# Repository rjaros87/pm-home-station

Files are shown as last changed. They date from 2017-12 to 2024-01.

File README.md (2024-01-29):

_Language versions:_\
EN (https://github.com/rjaros87/pm-home-station) 
PL (https://translate.googleusercontent.com/translate_c?sl=en&tl=pl&u=https://github.com/rjaros87/pm-home-station)
DE (https://translate.googleusercontent.com/translate_c?sl=en&tl=de&u=https://github.com/rjaros87/pm-home-station)

# Home use particulate matter sensor 

Since we live in big polluted cities the air quality is on a very poor level. But, the problem is not only connected to the big cities - even smaller cities and villages may suffer from air pollution.
That's why we've created this little project to let you build your own Particulate Matter monitoring station and use our open-source software so you could monitor the air quality in your place of living.

Let's live healthier life and start measuring the air quality and filtering it if necessary.

|  Android  | iPhone & Watch | Desktop |
|---|---|---|
|||<a href="https://github.com/rjaros87/pm-home-station/releases">Download and install</a>|

## Hardware Requirements

### USB version (supported by Android & Desktop apps)
- [PlanTower PMS7003](https://kamami.pl/czujniki-gazow/564008-plantower-pms7003-laserowy-czujnik-pylu-pm25.html) ~$26
- [ICD10 adapter with 10 pins(1.27 mm) to 6 pins (2.54 mm) (also called `G7 switch`)](https://kamami.pl/zlacza-inne/564553-adapter-idc10-127mm-na-zlacze-254mm-dla-czujnika-pms7003.html) ~$2
- UART to USB adapter:
  - [cheap PL2303](https://kamami.pl/konwertery-usb-uart-rs232/561382-modul-konwertera-usb-uart-rs232-ttl-z-ukladem-pl2303hx.html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) ~$2, or
  - [better quality FT232 (suggested for macOS for its superb compatibility)](https://kamami.pl/konwertery-usb-uart-rs232/561568-konwerter-usb-uart-ft232rl-waveshare.html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) ~$5
- [Female-Female wires 5 items (required for PL2303 otherwise optional since FT232 can be bought with wires already included)](https://kamami.pl/przewody-f-f/199418--przewody-polaczeniowe-f-f-roznokolorowe-17-cm-10-szt.html) ~$1-2
- [USB OTG cable](https://kamami.pl/przewody-usb/560191-przewod-adapter-microusb-otg.html) ~$1

### Bluetooth 2.0 (supported by Desktop app, possible support by Android app)
> Caution! Connectivity to the sensor over Bluetooth is currently only supported by the desktop application ran on macOS.

> Caution! If you want to connect from Apple iPhone or Apple Watch - please see Low Energy version (below)

- [PlanTower PMS7003](https://kamami.pl/czujniki-gazow/564008-plantower-pms7003-laserowy-czujnik-pylu-pm25.html) ~$26
- [ICD10 adapter with 10 pins(1.27 mm) to 6 pins (2.54 mm) (also called `G7 switch`)](https://kamami.pl/zlacza-inne/564553-adapter-idc10-127mm-na-zlacze-254mm-dla-czujnika-pms7003.html) ~$2
- [Female-Female wires 5 items](https://kamami.pl/przewody-f-f/199418--przewody-polaczeniowe-f-f-roznokolorowe-17-cm-10-szt.html) ~$1-2
- [Bluetooth UART HC-06](https://kamami.pl/moduly-bluetooth/198260-zestaw-bluetooth-z-modulem-hc-06-20edr-zasilany-3-6-6-v.html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) ~$7
- recycled old USB cable to provide power to Sensor and Bluetooth tandem

### Bluetooth Low Energy (supported by iOS app, possible support by Android app)
> Caution! Connectivity to the sensor over Bluetooth LE is currently only tested on the iOS application running on iPhone or Apple Watch. Multi-platform desktop support not planned in near feature.

- [PlanTower PMS7003](https://kamami.pl/czujniki-gazow/564008-plantower-pms7003-laserowy-czujnik-pylu-pm25.html) ~$26
- [ICD10 adapter with 10 pins(1.27 mm) to 6 pins (2.54 mm) (also called `G7 switch`)](https://kamami.pl/zlacza-inne/564553-adapter-idc10-127mm-na-zlacze-254mm-dla-czujnika-pms7003.html) ~$2
- [Bluetooth Low Energy UART HC-08](https://kamami.pl/moduly-bluetooth/562367-modhc-08-modul-bluetooth-hc-08.html) (includes wires) ~$7
- recycled old USB cable to provide power to Sensor and Bluetooth tandem

## Discount offers

You may want to use the following rebate coupon: __A9XS1FPF__ on purchases made on [KAMAMI.COM](https://kamami.com) or [KAMAMI.PL](https://kamami.pl) to get 5% OFF on orders which include PMS7003 (to be used only once for each buyer).

## Assemble the PM sensor

### USB version

1. Connect the PlanTower device with ICD10 adapter (~~like on photo below~~). 
> Caution! The pins on the PlanTower device are located in the top right corner. Numeration starts from the right top corner (1) and ends in the left bottom corner (10). 

2. Connect IDC10 adapter (bigger pins :smile:) to the UART-USB adapter. Wire connections are presented in a table below
> Caution! The adapter must have a separate VCC pin for 5V or a switch between 3.3V and 5V since the PlanTower device works on 5V voltage.

ICD10 adapter | UART-USB adapter
------------- | ----------------
VCC (5V)      | VCC (5V)
GND           | GND
RX            | TXD
TXD           | RXD

3. Connect the UART-USB adapter with a USB cable to your computer
> Caution! Refer to [this](#tested-platforms) section for remarks regarding your platform

4. Start the application and check the air quality of your environment :smile:

### Bluetooth version

1. Follow 1-3 steps of USB instruction above, but use your Bluetooth or Bluetooth LE module instead of UART-USB adapter

2. Cut off any old USB cable

3. Connect the power (5V) from USB cable or socket to Vcc and GND (2 most outside pins of USB plug, usually red 5V cable and black GND). You may need to shortcircuit data pin/wires (2 center pins) or connect them via ~200ohm resistor in order to be recognized by charger. Details can be found [here](http://pinouts.ru/Slots/USB_pinout.shtml "USB pinout").

## 3D printed enclosure

- 4x M3 x 25 machine screws with nuts are required to assemble the enclosure

- [Top v3 with hidden screws](/3d_models/top_v3_hidden_screws.stl)
- [Bottom v3 with hidden screws](/3d_models/bottom_v3_hidden_screws.stl)

or

- [Top v1](/3d_models/top_v1.stl)
- [Bottom v1](/3d_models/bottom_v1.stl)

or for FT232 usb-uart adapter

- [Top v4 with hidden screws for FT232 usb-uart adapter](/3d_models/top_v4_hidden_screws_ft232_adapter.stl)
- [Bottom v3 with hidden screws](/3d_models/bottom_v3_hidden_screws.stl)

Suggested printing parameters:
- Infill: 20%
- Resolution: 0.2
- Supports: No

> Caution! Make sure the soldered ends of the USB-UART pins (at the bottom of the adapter) are properly insulated from the sensor's metal case! Some adapters have them so long that they become too close to the sensor and may short-circuit the adapter. It's best to sand them off and use insulation tape.

## Assembly photos

The photo galleries of assembly:
- [PL2303 USB-to-UART version](https://rjaros87.github.io/pm-home-station-project/assembly/index.html "Assembly of pm-home-station using PL2303")
- [FT232 USB-to-UART version](https://rjaros87.github.io/pm-home-station-project/assembly-ft232/index.html "Assembly of pm-home-station using FT232")
- [UART-over-Bluetooth version](https://rjaros87.github.io/pm-home-station-project/assembly-bt/index.html "Assembly of pm-home-station over Bluetooth")

## Enclosure photos

The photo gallery of assembled device in 3d printed enclosure can be found [here](https://rjaros87.github.io/pm-home-station-project/enclosure/index.html "3d printed enclosure of pm-home-station").

## App Screenshots

The app screenshots gallery can be found [here](https://rjaros87.github.io/pm-home-station-project/screenshots/index.html "App screenshots of pm-home-station apps").

## Tested platforms

[See wiki page](https://github.com/rjaros87/pm-home-station/wiki/Tested-(supported)-platforms)

## Build and run

[See wiki page](https://github.com/rjaros87/pm-home-station/wiki/Building-&-Requirements)

## Contributing

[Contribution Guidelines](/CONTRIBUTING.md)

## License

[License GPL-3.0](/LICENSE)

## Authors

- [Radoslaw Gabiga](https://github.com/sanchin)
- [Radoslaw Jaros](https://github.com/rjaros87)
- [Piotr Skowronek](https://github.com/pskowronek)
- [Jerzy Łukjaniec](https://github.com/idf3d)

## Releases

The latest release versions can be found [here](https://github.com/rjaros87/pm-home-station/releases).

## Disclaimer

The information provided on this project is true and complete to the best of our knowledge. However, like various Do-It-Yourself (DIY) projects this DIY Project is at your own risk only.
As with any DIY project, lack of familiarity with the tools and process can be dangerous. We are not liable for any damage or injury resulting from the assembly or use of this project including but not limited to hardware damage, body injuries etc.

You have been warned.

<sub><sup>Google Play and the Google Play logo are trademarks of Google LLC.</sup></sub>

<sub><sup>Apple, the Apple logo, Apple Watch and iPhone are trademarks of Apple Inc., registered in the U.S. and other countries. App Store is a service mark of Apple Inc., registered in the U.S. and other countries.</sup></sub>

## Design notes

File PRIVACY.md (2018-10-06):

# Privacy Policy
The PMStation app is built as an Open Source app. This app is provided by the authors at no cost and is intended for use as is.

This page is used to inform visitors regarding our policies with the collection, use, and disclosure of Personal Information if anyone decided to use our applicaton.

If you choose to use our app, then you agree to the collection and use of information in relation to this policy. The Personal Information that we collect is used for providing and improving the service. We will not use or share your information with anyone except as described in this Privacy Policy.

### Information Collection and Use

For a better experience, while using our app, we may require you to provide us with certain personally identifiable information. The information that we request will be retained on your device and is not collected by us in any way.

The app does use third party services that may collect information used to identify you.

Link to privacy policy of third party service providers used by the app

* [Firebase Analytics](https://firebase.google.com/policies/analytics)
* [Crashlytics](https://docs.fabric.io/apple/fabric/data-privacy.html#data-collection-policies)

### Log Data

We want to inform you that whenever you use our application, in a case of an error in the app we collect data and information (through third party products) on your phone called Log Data. This Log Data may include information such as your device Internet Protocol (“IP”) address, device name, operating system version, the configuration of the app, the time and date of your use of the app, and other statistics.

### Cookies

Cookies are files with a small amount of data that are commonly used as anonymous unique identifiers. These are sent to your browser from the websites that you visit and are stored on your device's internal memory.

This app does not use these “cookies” explicitly. However, the app may use third party code and libraries that use “cookies” to collect information and improve their services.

### Security

We value your trust in providing us your Personal Information, thus we are striving to use commercially acceptable means of protecting it. But remember that no method of transmission over the internet, or method of electronic storage is 100% secure and reliable, and we cannot guarantee its absolute security.

### Links to Other Sites

This app may contain links to other sites. If you click on a third-party link, you will be directed to that site. Note that these external sites are not operated by us. Therefore, we strongly advise you to review the Privacy Policy of these websites. We have no control over and assume no responsibility for the content, privacy policies, or practices of any third-party sites or services.

### Changes to This Privacy Policy

We may update our Privacy Policy from time to time. Thus, you are advised to review this page periodically for any changes. We will notify you of any changes by posting the new Privacy Policy on this page. These changes are effective immediately after they are posted on this page.

### Contact Us

If you have any questions or suggestions about our Privacy Policy, do not hesitate to contact us.

This privacy policy page was created at [privacypolicytemplate.net](https://privacypolicytemplate.net/) and modified/generated by [App Privacy Policy Generator](https://app-privacy-policy-generator.firebaseapp.com/)

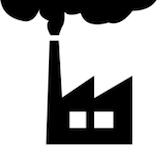
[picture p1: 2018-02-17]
iOS/PMMonitor/About.png

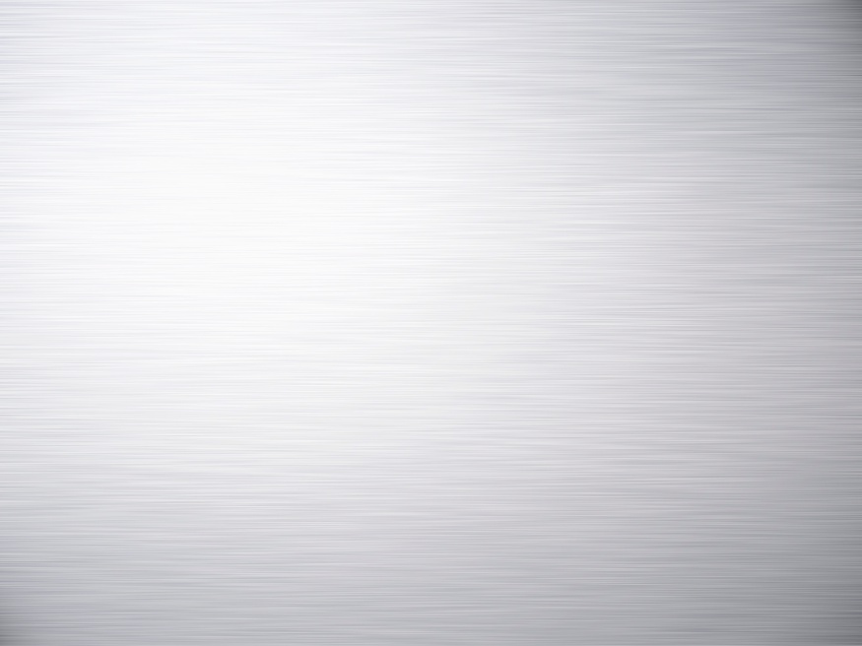
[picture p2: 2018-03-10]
desktop/src/main/resources/pmstation/bg.jpg

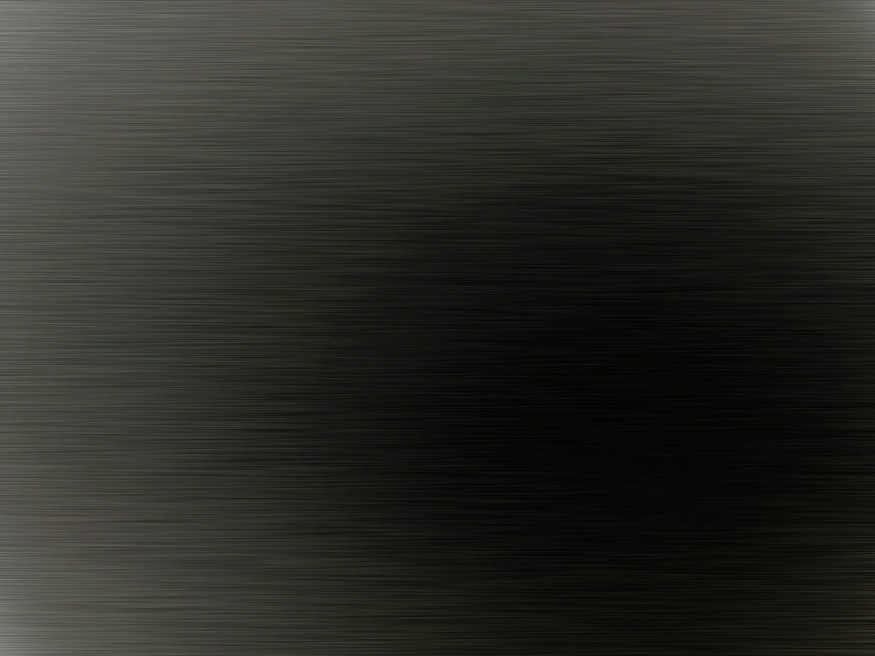
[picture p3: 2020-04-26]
desktop/src/main/resources/pmstation/bg-dark.jpg

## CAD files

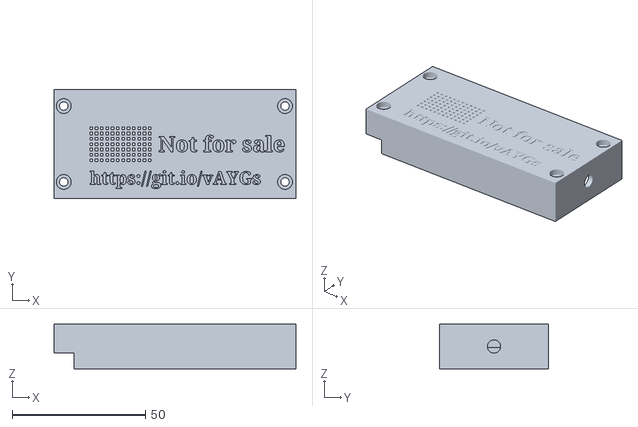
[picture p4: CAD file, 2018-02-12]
3d_models/top_v5_bluetooth_prototype.stl
90.7 x 40.9 x 16.8

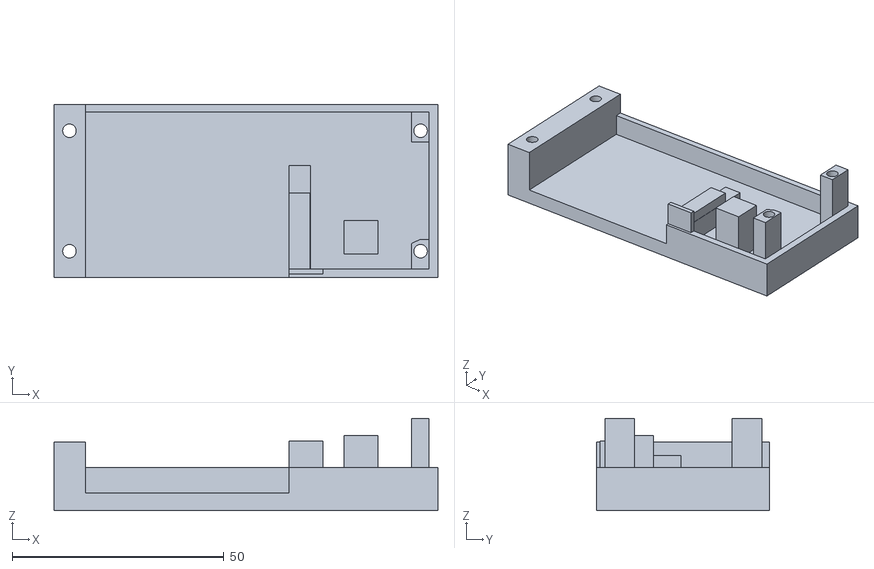
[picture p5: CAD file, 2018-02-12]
3d_models/bottom_v5_bletooth.stl
90.7 x 40.8 x 21.8

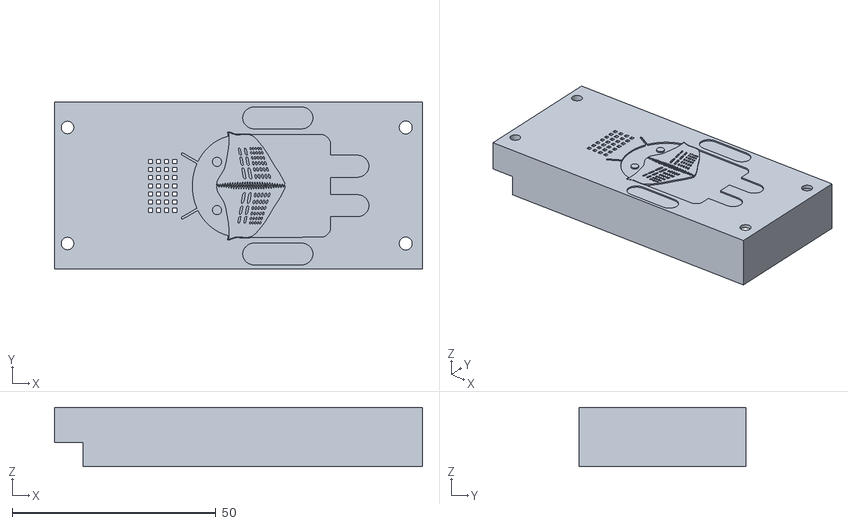
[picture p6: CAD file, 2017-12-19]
3d_models/top_v1.stl
90.3 x 40.9 x 14.6

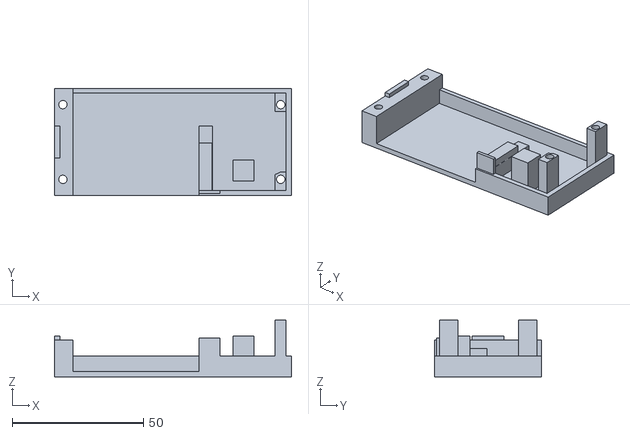
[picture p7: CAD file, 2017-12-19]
3d_models/bottom_v1.stl
90.3 x 40.9 x 21.6

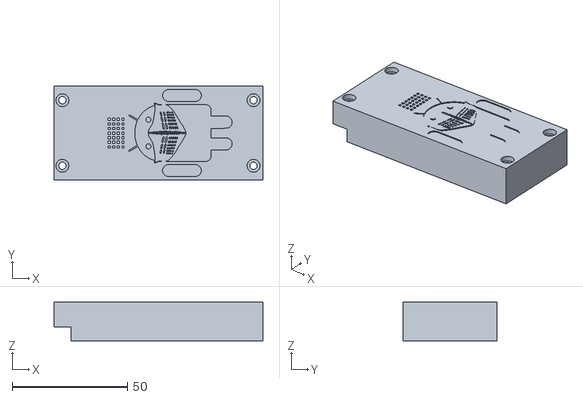
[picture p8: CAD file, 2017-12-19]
3d_models/top_v3_hidden_screws.stl
90.7 x 40.9 x 16.8

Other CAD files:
3d_models/top_v4_hidden_screws_ft232_adapter.stl
3d_models/bottom_v3_hidden_screws.stl

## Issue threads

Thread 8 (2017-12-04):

[Desktop enhancement] Average measurments for last 3h, 6h?

dareknowak, 2017-12-04:
Is it possible to add additional measurement view, where average values are displayed above/below the "last measurements" - _graphical view is not necessary_. Measurements calculated for max 12h/24h, with preselection e.g. 2/6/12/24h.

Store mechanism would have to be implemented though...

*marked that as an enhancement

pskowronek, 2017-12-12:
A simple average i.e. mean can be calculated as a running/moving mean w/o storing all the samples, therefore we could even use our configuration storage (in Desktop version) to keep the sum and a number of samples. However, median would be a better choice I guess, but it would require storing of all the samples and in such a case the config is not the right place :)

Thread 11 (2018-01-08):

[Desktop] configurable port to use

pskowronek, 2018-01-08:
Currently for each OS a basic autodetection is being done.

It might be useful to allow the user to specify which port to use, either directly by port name (for example "com1" for Windows) or by port description (provided by OS if supported and available).
For such a case the autodetection could be left as the last resort.

pskowronek, 2018-02-28:
committed: 36d7454671a96c28e40ceceb220ec57621dd94d2

Configurable by just port name, should be enough for now.

pskowronek, 2018-02-28:
done

Closed 2018-02-28.

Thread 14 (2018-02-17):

[Android] BT LE Support?

idf3d, 2018-02-17:
Does Android Application supports BT LE? Could please anyone with Android device check it and add such support if not yet supported?

idf3d, 2018-02-17:
Looks like @sanchin 'owns' android part. Radek, could you please check? :)

sanchin, 2018-02-17:
Well, I don't have to check, since I know I didn't implement it ;D

I'll create something once my BT arrives.

SzymonCierniewski, 2018-12-09:
@sanchin Great work! Thank you! :smile:
Could you confirm that BT LE is already supported?

It looks like it's implemented, but does it work?
https://github.com/rjaros87/pm-home-station/commit/3d2de061efee599384d86f1d1289bd58b88c1b7d

rjaros87, 2018-12-09:
@SzymonCierniewski with my Motorola G5S works :)

sanchin, 2018-12-09:
Well...yeah, it kinda works. It's not yet "production ready" as the rest of the guys were supposed to test it almost a year ago and I waited for them ;)

Currently, you have to set your device's MAC address in the settings to connect, there's no discovery. For whatever reason - my phone can't find my BT UART, so developing the discovery is kinda tricky.

SzymonCierniewski, 2018-12-12:
Thank you! I will test it soon :smile:

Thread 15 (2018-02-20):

[Desktop-Win10] checked "show in system tray" causes app to hang on all multiple monitors under win10

dareknowak, 2018-02-20:
Noticed some issue with desktop app, release 1.1.0 and native virtual desktop capability under windows 10

env:
windows 10 enterprise

steps to reproduce:
1. open app
2. mark the "show in system tray"
3. restart app
4. system tray app icon is visible
5. switch to some other virtual desktop under windows 10,
(x) application is still there, visible on all virtual desktops,
(/) should be visible only under one virtual desktop

regards
D.

pskowronek, 2018-02-20:
pls close if the fix works for you

dareknowak, 2018-02-21:
Superb.

Closed 2018-02-21.

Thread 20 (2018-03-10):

[D] brushed amelinium does not fill the resized window

dareknowak, 2018-03-10:
Img attached.

To reproduce:

1. Open windows desktop version
2. Resize window
3. Background does not fill resized window

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

pskowronek, 2018-03-10:
> Background does not fill resized window
The background image is definite so... it must end somewhere and ... because Sun/Oracle was unable to fix Frame#setMaximumSize and its cooperation with Layout Manger for like 20yrs you can see that effect on Windows and probably on Linux. Just don't resize too much or use OSX :P

dareknowak, 2018-03-11:
works like a charm and looks!

Closed 2018-03-10.

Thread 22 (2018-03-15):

[Desktop] Headless mode for desktop app

pskowronek, 2018-03-15:
Allow for headless mode in desktop app (i.e. command line mode)

pskowronek, 2018-03-15:
Added the following command:
 -c,--headless   headless mode (cli mode) - autostarts measurements based on config

To log into csv file add the following entries to config file:
csv.log.file = /path/to/file.csv
csv.log.enabled = true

The above command starts to measure until either sensor disconnected or app killed (or interrupted).

rjaros87, 2018-03-16:
Add above knowledge in README.md ;)

pskowronek, 2018-03-16:
- Moved some bits from README.md to WIKI
- Added info about headless mode on the following wiki page: https://github.com/rjaros87/pm-home-station/wiki/Features

Closed 2018-03-16.

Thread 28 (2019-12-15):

[Android&Desktop]Nova PM SDS011

0merta, 2019-12-15:
First of all, great job for this project.

I think it would be great to have support for Nova PM SDS011

pskowronek, 2019-12-16:
We don't currently plan to add this device as it doesn't bring any new features. We're now considering PMS5003ST (#29) as it can provide temp, humidity & formaldehyde readings.

rjaros87, 2019-12-17:
@0merta you can always contribute :)

Closed 2019-12-24.

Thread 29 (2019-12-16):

New PMS5003ST

rjaros87, 2019-12-16:
Maybe we should consider to test new device? @pskowronek @sanchin  @idf3d
PMS5003**ST** provide additionally measurements of:
- Formaldehyde
- Temperature
- Humidity

Device: https://pl.aliexpress.com/item/4000036196650.html
(Optional) Adapter https://pl.aliexpress.com/item/33040162499.html

pskowronek, 2019-12-16:
+1

pskowronek, 2020-01-02:
Manual in english:
https://www.thaieasyelec.com/downloads/ESEN298/PMS5003ST_Datasheet.pdf

pskowronek, 2020-04-26:
merged to master

Closed 2020-04-26.

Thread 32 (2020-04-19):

[desktop] Introduce fullscreen & kiosk modes

pskowronek, 2020-04-19:
Introduce fullscreen & kiosk modes via command line arguments (-k, --kiosk, -f, --fullscreen).

- Fullscreen mode makes the window maximized (its dimensions are now saved to properties on exit)
- Kiosk mode makes the window exclusive in the UI (if supported by OS, falls back to fullscreen otherwise). In this mode control panel with buttons is hidden, partially because such mode won't allow for modals, secondly it should not be interactive (Kiosk right). Double click or ESC in such mode exits this mode into Fullscreen mode.

pskowronek, 2020-04-19:
committed to "new_device" branch

Closed 2020-04-19.

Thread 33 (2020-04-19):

[desktop] Autodetect RPi built-in UART and its serial port (Raspbian)

pskowronek, 2020-04-19:
Autodetect RPi built-in UART and its serial port (Raspbian) by looking for /dev/ttyS0 (confirmed on RPi Zero). Useful if PMS device is directly connected to PIN 8 & 10 (GPIO 14 & 15) of RPi.

Built-in UART in RPi can be enabled by editing /boot/config.txt and setting: enable_uart=1 or via command raspi-config.

pskowronek, 2020-04-19:
committed to 'new_device' branch

Closed 2020-04-19.

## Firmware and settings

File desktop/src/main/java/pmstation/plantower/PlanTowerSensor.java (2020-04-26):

/*
 * pm-home-station
 * 2017 (C) Copyright - https://github.com/rjaros87/pm-home-station
 * License: GPL 3.0
 */
package pmstation.plantower;

import java.util.ArrayList;
import java.util.List;
import java.util.concurrent.Executors;
import java.util.concurrent.ScheduledExecutorService;
import java.util.concurrent.ScheduledFuture;
import java.util.concurrent.TimeUnit;

import org.slf4j.Logger;
import org.slf4j.LoggerFactory;

import pmstation.core.plantower.IPlanTowerObserver;
import pmstation.core.plantower.ParticulateMatterSample;
import pmstation.core.plantower.PlanTowerDevice;
import pmstation.serial.SerialUART;

public class PlanTowerSensor {
    
    private static final Logger logger = LoggerFactory.getLogger(PlanTowerSensor.class);
    
    private static final long DEFAULT_INTERVAL = 3000L;
    private static final long MEASUREMENTS_INITIAL_DELAY = 2000L;

    private final List<IPlanTowerObserver> planTowerObserver;
    private final SerialUART serialUART;
    private final ScheduledExecutorService scheduledExecutor;
    private ScheduledFuture<?> scheduledMeasurements = null;
    private long interval = -1;
    private PlanTowerDevice device = null;

    public PlanTowerSensor() {
        serialUART = new SerialUART();
        planTowerObserver = new ArrayList<>();
        scheduledExecutor = Executors.newScheduledThreadPool(2);
    }

    public boolean connectDevice() {
        notifyAboutConnecting();
        boolean openPort = serialUART.openPort();
        if (openPort) {
            logger.debug("Waking up the device...");
            serialUART.writeBytes(PlanTowerDevice.MODE_WAKEUP);
            delay();
            serialUART.writeBytes(PlanTowerDevice.MODE_ACTIVE);
            delay();
            notifyAboutConnection();
        } else {
            disconnectDevice();
        }
        return openPort;
    }

    public void disconnectDevice() {
        notifyAboutDisconnecting();
        if (scheduledMeasurements != null) {
            scheduledMeasurements.cancel(true);
        }
        if (serialUART.isConnected()) {
            logger.debug("Sleeping the device...");
            serialUART.writeBytes(PlanTowerDevice.MODE_PASSIVE);
            delay();    // seems to be required... otherwise it won't go to sleep
            serialUART.writeBytes(PlanTowerDevice.MODE_SLEEP);
            delay();
            serialUART.closePort();
        }
        notifyAboutDisconnection();
    }

    public void startMeasurements() {
        startMeasurements(DEFAULT_INTERVAL);
    }
    
    public synchronized void startMeasurements(long interval) {
        if (scheduledMeasurements != null && !scheduledMeasurements.isDone()) {
            if (this.interval == interval) {
                logger.info("Ignoring re-scheduling since the interval is the same as previous one");
                return;
            } else {
                logger.info("Going to cancel scheduled measurement task as interval change is requested");
                scheduledMeasurements.cancel(true);
            }
        }
        logger.info("Scheduling measurements at interval: {}ms...", interval);
        scheduledMeasurements = scheduledExecutor.scheduleAtFixedRate(getMeasurementsRunnable(), MEASUREMENTS_INITIAL_DELAY, interval, TimeUnit.MILLISECONDS);
        this.interval = interval;
    }

    public void addObserver(IPlanTowerObserver observer) {
        planTowerObserver.add(observer);
    }
    
    public boolean isConnected() {
        return serialUART.isConnected();
    }
    
    public String portDetails() {
        return serialUART.portDetails();
    }
    
    public void waitUntilDisconnected() {
        Thread shutdownHook = new Thread(() -> disconnectDevice());
        Runtime.getRuntime().addShutdownHook(shutdownHook);
        while (true) {
            try {
                if (scheduledMeasurements.isCancelled() || scheduledMeasurements.isDone()) {
                    logger.info("Measurements finished for whatever reason, bailing out");
                    return;
                }
                Thread.sleep(100);
            } catch (InterruptedException ex) {
                Thread.currentThread().interrupt();
                throw new RuntimeException(ex);
            }
        }
    }

    private Runnable getMeasurementsRunnable() {
        return () -> {
            try {
                if (serialUART.isConnected()) {
                    for (int i = 0; i < 3 && device == null; i++) {
                        byte[] sampleData = serialUART.readBytes(150); // more than 3 times more than max of expected data length
                        if (sampleData != null) {
                            device = new PlanTowerDevice(sampleData);
                            if (device.modelIdentified()) {
                                logger.info("PlanTower model: {}", device.model());
                                break;
                            } else {
                                logger.info("PlanTower model not identified...");
                            }
                        } else {
                            logger.info("Data from serial UART is null.");
                            scheduledMeasurements.cancel(false);
                            notifyAboutDisconnection();
                            return;
                        }                            
                    }

                    if (!device.modelIdentified()) {
                        logger.info("Unable to identify device model based on its data (a sudden device disconnection?)");
                        scheduledMeasurements.cancel(false);
                        notifyAboutDisconnection();
                        device = null; // reset, retry another time
                        return;
                    }
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

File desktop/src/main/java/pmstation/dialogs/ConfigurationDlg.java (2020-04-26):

/*
 * pm-home-station
 * 2017 (C) Copyright - https://github.com/rjaros87/pm-home-station
 * License: GPL 3.0
 */
package pmstation.dialogs;

import java.awt.Container;
import java.awt.Dialog.ModalityType;
import java.awt.Font;
import java.awt.SystemTray;
import java.awt.event.ActionEvent;
import java.awt.event.ActionListener;
import java.awt.event.ItemEvent;
import java.awt.event.ItemListener;
import java.awt.event.KeyEvent;
import java.awt.event.KeyListener;
import java.awt.event.MouseAdapter;
import java.awt.event.MouseEvent;
import java.io.File;
import java.util.ArrayList;
import java.util.HashSet;
import java.util.Set;

import javax.swing.DefaultListModel;
import javax.swing.GroupLayout;
import javax.swing.GroupLayout.Alignment;
import javax.swing.JButton;
import javax.swing.JCheckBox;
import javax.swing.JDialog;
import javax.swing.JFileChooser;
import javax.swing.JFrame;
import javax.swing.JLabel;
import javax.swing.JList;
import javax.swing.JPanel;
import javax.swing.JScrollPane;
import javax.swing.JSpinner;
import javax.swing.JTabbedPane;
import javax.swing.JTextField;
import javax.swing.LayoutStyle.ComponentPlacement;
import javax.swing.ListModel;
import javax.swing.ListSelectionModel;
import javax.swing.ScrollPaneConstants;
import javax.swing.SpinnerNumberModel;
import javax.swing.SwingConstants;
import javax.swing.SwingUtilities;
import javax.swing.UIManager;
import javax.swing.border.TitledBorder;
import javax.swing.event.ChangeEvent;
import javax.swing.event.ChangeListener;
import javax.swing.event.DocumentEvent;
import javax.swing.event.DocumentListener;
import javax.swing.filechooser.FileNameExtensionFilter;

import org.apache.commons.lang3.SystemUtils;
import org.slf4j.Logger;
import org.slf4j.LoggerFactory;

import pmstation.configuration.Config;
import pmstation.configuration.Constants;
import pmstation.serial.SerialUART;

public class ConfigurationDlg {

    @SuppressWarnings("unused")
    private static final Logger logger = LoggerFactory.getLogger(ConfigurationDlg.class);

    private JFrame mainFrame;
    private String title;
    private JSpinner textInterval;
    private JDialog frame = null;
    private JTextField textAddDevice;

    public ConfigurationDlg(JFrame parent, String title) {
        this.mainFrame = parent;
        this.title = title;
    }

    /**
     * @wbp.parser.entryPoint
     */
    public void show() {
        if (frame != null) {
            frame.toFront();
            frame.requestFocus();
            return;
        }
        frame = new JDialog(mainFrame, title, ModalityType.APPLICATION_MODAL);
        frame.setResizable(false);
        frame.setBounds(350, 350, 588, 496);
        frame.setDefaultCloseOperation(JDialog.DISPOSE_ON_CLOSE);
        frame.setLocationRelativeTo(mainFrame);
        Container mainCfg = frame.getContentPane();

        JTabbedPane tabbedPane = new JTabbedPane(JTabbedPane.TOP);
        mainCfg.add(tabbedPane);

        JPanel panelGeneral = new JPanel();
        panelGeneral.setBorder(new TitledBorder(null, "<html><b>General</b></html>", TitledBorder.LEADING,
                TitledBorder.TOP, null, null));

        JPanel panelUI = new JPanel();
        panelUI.setBorder(new TitledBorder(null, "<html><b>User Interface</b></html>", TitledBorder.LEADING,
                TitledBorder.TOP, null, null));

        JPanel panelDevice = new JPanel();
        panelDevice.setBorder(new TitledBorder(null, "<html><b>Device</b></html>", TitledBorder.LEADING,
                TitledBorder.TOP, null, null));

        JPanel panelBottom = new JPanel();
        panelBottom.setBorder(null);

        tabbedPane.addTab("General", panelGeneral);
        tabbedPane.addTab("User Interface", panelUI);
        tabbedPane.addTab("Device", panelDevice);
        panelDevice.setLayout(null);

        JList<String> listAvailableDevices = new JList<String>();
        listAvailableDevices.setToolTipText("The list of available devices found in the system");
        JLabel lblWarnUserOSX = new JLabel(
                "<html>Warn before close / disconnect if device is not detached:<br/><small><i>- a workaround for macOS and faulty PL2303 drivers</i></small></html>");
        lblWarnUserOSX.setBounds(6, 22, 358, 29);
        panelDevice.add(lblWarnUserOSX);
        lblWarnUserOSX.setEnabled(SystemUtils.IS_OS_MAC_OSX);

        JCheckBox chbxWarnOSX = new JCheckBox("");
        chbxWarnOSX.setBounds(510, 22, 30, 23);
        panelDevice.add(chbxWarnOSX);
        chbxWarnOSX.setEnabled(SystemUtils.IS_OS_MAC_OSX);
        chbxWarnOSX.setSelected(!SystemUtils.IS_OS_MAC_OSX || Config.instance().to()
                .getBoolean(Config.Entry.WARN_ON_OSX_TO_DETACH.key(), SystemUtils.IS_OS_MAC_OSX));
        chbxWarnOSX.addMouseListener(new MouseAdapter() {
            @Override
            public void mouseClicked(MouseEvent e) {
                Config.instance().to().setProperty(Config.Entry.WARN_ON_OSX_TO_DETACH.key(), chbxWarnOSX.isSelected());
            }
        });

        JLabel lblPreferredDevices = new JLabel(
                "<html>Preferred devices <small>(priority top -> down)</small>:</html>");
        lblPreferredDevices.setBounds(6, 55, 260, 16);
        panelDevice.add(lblPreferredDevices);

        JList<String> listPreferredDevices = new JList<String>();
        listPreferredDevices.setToolTipText("The list of preferred devices");
        JScrollPane listPreferredDevicesScroller = new JScrollPane();
        listPreferredDevicesScroller.setViewportView(listPreferredDevices);
        listPreferredDevicesScroller.setHorizontalScrollBarPolicy(ScrollPaneConstants.HORIZONTAL_SCROLLBAR_NEVER);
        listPreferredDevicesScroller.setBounds(6, 75, 490, 90);
        listPreferredDevices.setModel(getPreferredDevices());
        panelDevice.add(listPreferredDevicesScroller);

        JButton btnPriorityUp = new JButton("⇑");
        btnPriorityUp.setHorizontalTextPosition(SwingConstants.CENTER);
        btnPriorityUp.setAlignmentY(0.0f);
        btnPriorityUp.setToolTipText("Increase priority");
        btnPriorityUp.setBounds(500, 72, 50, 33);
        btnPriorityUp.addMouseListener(new MouseAdapter() {
            @Override
            public void mouseClicked(MouseEvent e) {
                int idx = listPreferredDevices.getSelectedIndex();
                if (idx > 0) {
                    swapInList((DefaultListModel<String>) listPreferredDevices.getModel(), idx, idx - 1);
                    listPreferredDevices.setSelectedIndex(idx - 1);
                    listPreferredDevices.ensureIndexIsVisible(idx - 1);
                    savePreferredDevices(listPreferredDevices);
                }
            }
        });
        panelDevice.add(btnPriorityUp);
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

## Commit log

2017-11-19 Added Firebase, sleep and wakeup calls for the sensor.
2017-12-19 Add 3D enclosure for the PlanTower device & the UART-USB adapter
    [bottom_v1.stl, top_v1.stl]
2017-12-19 Reflow Swing UI + debug to trace app hang up on OSX when reconnecting
    Reflow Swing UI + debug to trace app hang up on OSX when reconnecting
2017-12-19 Add logo to 3d model
    [top_v1.stl]
2017-12-19 Add 3d model with hidden screws and pm-station-logo.svg
    [bottom_v2_hidden_screws.stl, top_v2_hidden_screws.stl]
2017-12-19 Statusbar + fix not to write when not connected
    [PlanTowerSensor.java, SerialUART.java]
2017-12-19 Fix for ConfigurationDlg L&F on Windows + NPE fix
    [ConfigurationDlg.java, SerialUART.java]
2017-12-19 Fix for ConfigurationDlg L&F on Windows... final
    [ConfigurationDlg.java]
2017-12-19 Fix issues #6 & #7 - always-on-top & typo
    [ConfigurationDlg.java]
2017-12-19 Warning for OSX to workaround driver hangup
    [ConfigurationDlg.java, PlanTowerSensor.java]
2017-12-19 Fix to skip data accumulated/buffered between measurements
    [PlanTowerSensor.java, SerialUART.java]
2017-12-19 Fix main window's buttons size with icon to look the same as on OSX
2017-12-19 Handle sensor disconnection + fix chart lists to remove old data
    [PlanTowerSensor.java]
2017-12-19 Update 3d model with hidden screws
    [bottom_v2_hidden_screws.stl, bottom_v3_hidden_screws.stl, top_v2_hidden_screws.stl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]
2017-12-19 Moving resource related code to ResourceHelper. Hide for now the image from About html - TBD later
    [top_v3_hidden_screws.stl]
2017-12-19 Fix for imgs in html of About + info about FT232 + updates regarding disconnection
    [PlanTowerSensor.java]
2017-12-19 README.md FT232 clarifications, added support for sensor over bluetooth
2017-12-19 README.md updated about OTG remarks and USB power for BT version
2017-12-19 [D] Better BT support + enter device into sleep when closing
2017-12-21 Small fixes: readme.md regarding jar command + traffic logging
    [SerialUART.java]
2017-12-21 Add 3d model for FT232 USB-UART adapter
    [top_v4_hidden_screws_ft232_adapter.stl]
2018-01-02 FT232 assembly photos
2018-02-12 Add 3d model for bluetooth adapter (prototype)
    [bottom_v5_bletooth.stl, top_v5_bluetooth_prototype.stl]
2018-02-20 Fixed issues on Windoze, mainly: #17, #16, #15 + fixed conf issue on Ubuntu 17 when/where System Tray is not supported
    [ConfigurationDlg.java]
2018-02-21 [D] rename config to follow project name + fix for system tray related behavior on Ubuntu 17.10
    [ConfigurationDlg.java]
2018-02-25 [D] UI Fixes: chart grows vertically w/o limit, measurments panel tweaks + com port details
    [PlanTowerSensor.java, SerialUART.java]
2018-02-28 [D] Avoid re-trying already checked ports while autoconnecting
    [SerialUART.java]
2018-03-10 [D] Workaround for Windoze issue with window max-size and background img (upscaling the image in such a case) #20
2018-03-16 [D] Minor fix to configuration dlg regarding CSV
    [ConfigurationDlg.java]
2018-03-25 Sensor changed to a Service, initial BLE service impl
2018-10-03 Fix 'sensor disconneted' on status bar
2019-11-25 Stop pestering users for agreement every time the device is connected
2019-11-25 Add PL2303 and CP210X to usb-device list
2020-01-19 [Draft #29] New PMS5003ST device
2020-02-16 PMS5003ST temperature bytes->signed int fix + Desktop UI minor updates + libs upgrade to the newest ones, #29
2020-02-16 PMS5003ST temperature bytes->signed int fix (ugh), #29
2020-02-16 PMS5003ST added checksum verification for both PMS + model revision + error code logging to CSV and Console + fix for temperature - suprisingly temperature can be negative in Celcius degrees :P, #29
2020-02-17 PMS5003ST checksum fixed to cover error bits, using checksum to verify frames used for model id'n #29
    [PlanTowerSensor.java, SerialUART.java]
2020-02-18 Fixed some typos in code + sentance rephrase in Confg dlg
    [ConfigurationDlg.java]
2020-02-23 Some cosmetic visual corrections for Configuration dlg to try to address Win10 issues
    [ConfigurationDlg.java]
2020-02-23 Configuration dlg fix code fomatting
    [ConfigurationDlg.java]
2020-02-23 Configuration dlg fixes for crazy autogenerated code
    [ConfigurationDlg.java]
2020-04-19 Introducing fullscreen & kiosk modes #32 + fixes for better frame resize, WiP
2020-04-19 In Kiosk mode hide control buttons #32
2020-04-19 Autodetect RPi built-in UART and its serial port #33
2020-04-29 [iOS] Charts framework is now git-submodule.
2024-03-24 Revive Android (#42)
    * Revive Android
    * Fix part 1
    * Fix for using com.apple.eawt under mac
    * Travis to use JDK20 for Desktop
    * Try to avoid 'assemble' in Travis
    * Fixed createExe (launch4j)
    * Android app works on simulator
    * Fix for using com.apple.eawt under mac for JAR
    * Android licenses
    * Android licenses
    * Android licenses
    * Android licenses
    * Android licenses
    * Android travis script
    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
